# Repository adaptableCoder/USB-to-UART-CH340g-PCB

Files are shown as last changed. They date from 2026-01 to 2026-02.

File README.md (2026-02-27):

# USB to UART Converter (CH340G)

A compact **USB-to-UART adapter** based on the **CH340G**, implemented as a **USB-A edge connector board**.
Fabrication files have been generated; board fabrication is pending.

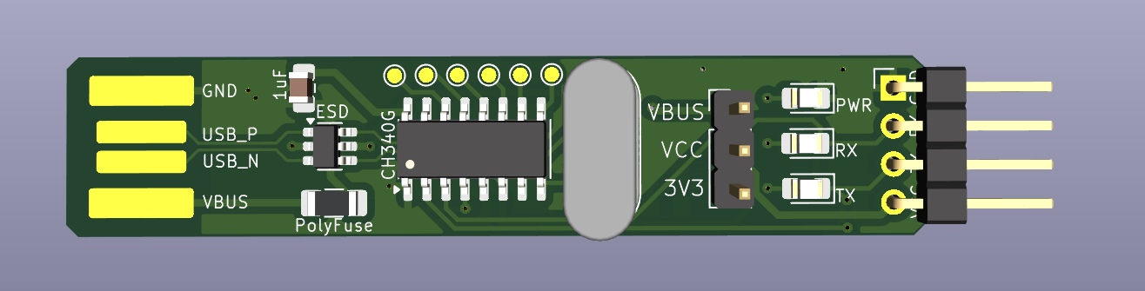
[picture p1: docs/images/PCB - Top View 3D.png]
PCB Top 3D View

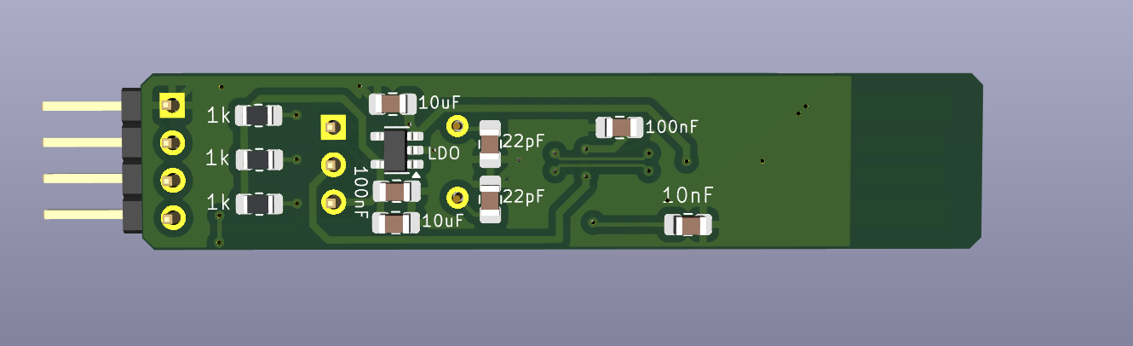
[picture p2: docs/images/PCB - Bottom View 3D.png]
PCB Bottom 3D View

---

## Overview

This project implements a reliable USB-to-UART interface suitable for development, debugging, and embedded bring-up tasks.
Unlike typical breakout boards, this design uses a **USB-A edge connector**, allowing direct insertion into a host USB port without a cable.

The board supports both **5 V and 3.3 V UART logic levels** via jumper selection.

---

## Key Features

* CH340G USB-to-UART bridge
* USB-A **edge connector** (ENIG finish, bevelled)
* Jumper-selectable UART logic level (5 V / 3.3 V)
* On-board 3.3 V LDO
* USB ESD protection
* Polyfuse on VBUS for over-current protection
* Status LEDs (Power, TX, RX)
* RTS / CTS / DTR / DSR signals exposed
* 2-layer PCB, 1.6 mm thickness

---

## Design Tools Used

- KiCad (schematic capture, PCB layout, Gerber generation)

---

## Design Highlights

* **Grounding strategy**

  * Ground stitching vias near USB connector, ESD, and IC
  * Controlled return paths for high-speed signals

* **Clock integrity**

  * 12 MHz crystal placed close to XI/XO pins
  * Symmetric routing and tight loop area
  * Dedicated ground vias for crystal capacitors

* **Manufacturability**

  * ENIG finish selected for USB edge reliability
  * Bevelled edge specified for connector durability
  * Clean DRC-verified Gerber output

---

## Repository Structure

```
usb-to-uart-ch340g-pcb/
├── README.md
├── LICENSE
├── docs/
│   ├── images/
│   └── design-notes.md
├── schematic/
│   └── usb-to-uart-ch340g_schematic.pdf
├── pcb/
│   └── layout_screenshots/
├── fabrication/
│   ├── USB-to-UART-CH340G_Gerbers.zip
│   └── fab-notes.txt
├── datasheet/
│   └── CH340G_datasheet.pdf
└── KiCAD files/
    ├── usb-to-uart.kicad_pro
    ├── usb-to-uart.kicad_sch
    ├── usb-to-uart.kicad_prl
    └── usb-to-uart.kicad_pcb
```
---

## Fabrication Details

* Layers: 2
* Board thickness: 1.6 mm
* Copper weight: 1 oz
* Surface finish: ENIG
* USB edge connector: bevelled
* Solder mask: standard

---

## References and Attribution

* The USB-A edge connector footprint is **adapted from an open-source KiCad footprint library**. The original library is referenced here for attribution: https://github.com/vasya-zh/PCB-Edge-USB-connector-KiCad-library

* Component selection and implementation follow the **WCH CH340G datasheet** and standard USB Full-Speed design guidelines.

* Some YouTube tutorials and online articles on USB-to-UART designs were consulted during development.<br/>
[PCB Cupid](https://www.youtube.com/playlist?list=PLn6004q9oeqGl91KifK6xHGuqvXGb374G) <br/>
[Hardik Seth](https://www.youtube.com/@DIYwithHardik) <br/>
[Electronics Globe](https://www.youtube.com/@electronicsglobeofficial)

---

## License

This project is released under the **MIT License** unless stated otherwise.
Third-party references retain their respective licenses.

---

## Notes

This project was built as a **practical hardware design exercise**, with emphasis on finishing a complete, manufacturable PCB rather than producing a minimal demo board.
Future revisions may explore USB-C support or auto-voltage sensing.

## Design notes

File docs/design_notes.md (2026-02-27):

# Design Notes — USB to UART Converter (CH340G)

This document summarizes the key design decisions and constraints considered while developing this USB-to-UART converter.

---

## USB Interface

- USB Full-Speed (12 Mbps) interface implemented using CH340G.
- USB-A edge connector used instead of a cabled receptacle to reduce mechanical complexity and improve robustness.
- ENIG surface finish and bevelled edge specified for reliable insertion and wear resistance.
- USB D+ / D− routed as a short, parallel pair on the top layer with:
  - Consistent spacing
  - Continuous ground reference underneath

---

## Grounding Strategy

- Bottom copper layer used as the primary ground reference plane.
- Ground plane continuity preserved under USB data lines and crystal region.
- Ground stitching vias added near:
  - USB GND finger
  - ESD protection device
  - CH340G ground pins
  - Crystal load capacitors

This minimizes loop inductance and improves EMI and ESD performance.

---

## Clocking (Crystal Oscillator)

- External 12 MHz crystal used, as recommended for CH340G.
- Crystal placed close to XI/XO pins with symmetric routing.
- Load capacitors placed adjacent to the crystal.
- Each capacitor has a dedicated via to the ground plane.
- No signal or power routing under the crystal region.

---

## Power Architecture

- USB VBUS protected using a PPTC polyfuse.
- CH340G powered directly from 5 V (VBUS), following reference designs.
- Internal 3.3 V regulator output (V3 pin) used only for decoupling, not as a system rail.
- External LDO generates 3.3 V for UART header power and external targets.
- Jumper allows selection of UART header supply (5 V or 3.3 V) without affecting CH340G supply.

---

## UART Interface

- TX, RX, RTS, CTS, DTR, and DSR signals exposed via testing points.
- UART logic level selectable between 5 V and 3.3 V using a jumper.

---

## Protection and Reliability

- USB ESD protection diode placed close to connector.
- Polyfuse limits over-current from USB host.
- Decoupling and bulk capacitors placed close to their respective loads.

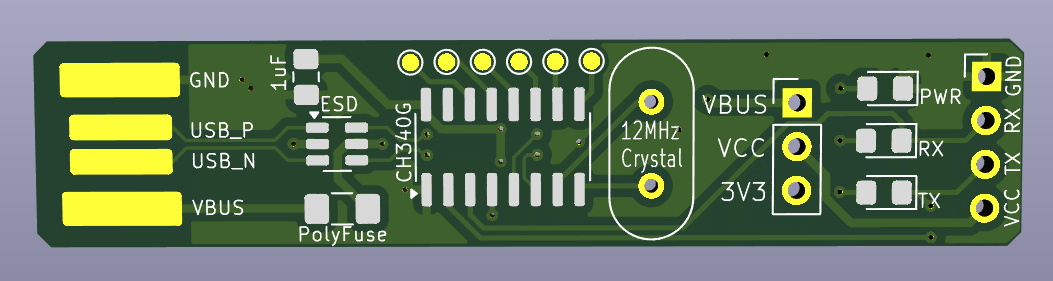
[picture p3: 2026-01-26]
docs/images/PCB - Top View.png

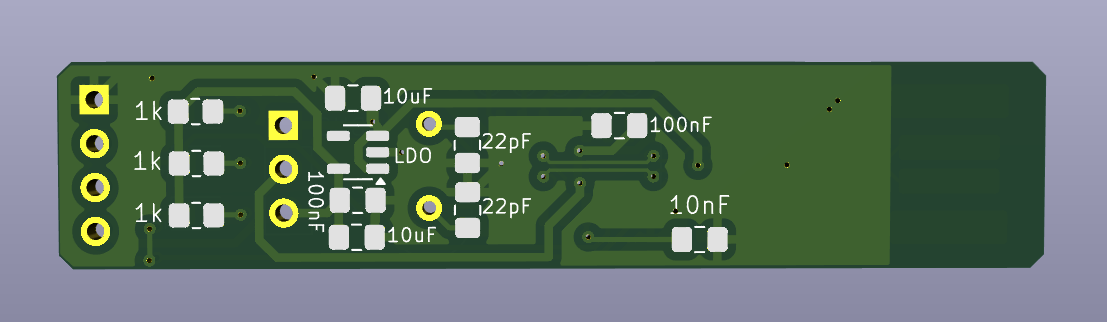
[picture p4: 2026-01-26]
docs/images/PCB - Bottom View.png

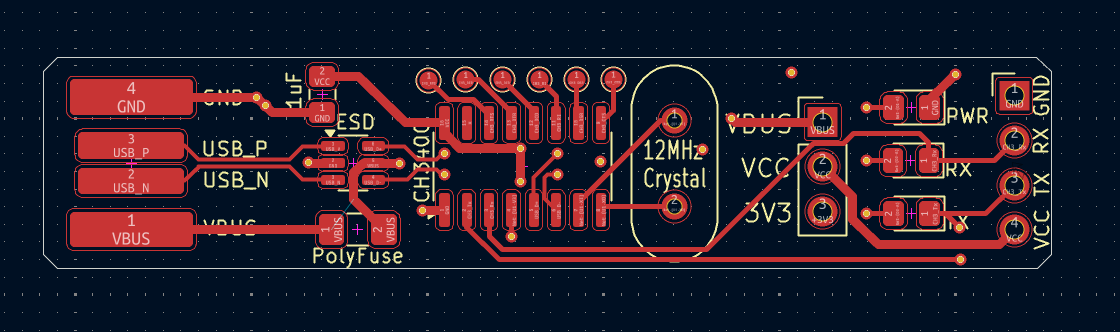
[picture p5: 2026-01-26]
pcb/layout_screenshots/Top Routing.png

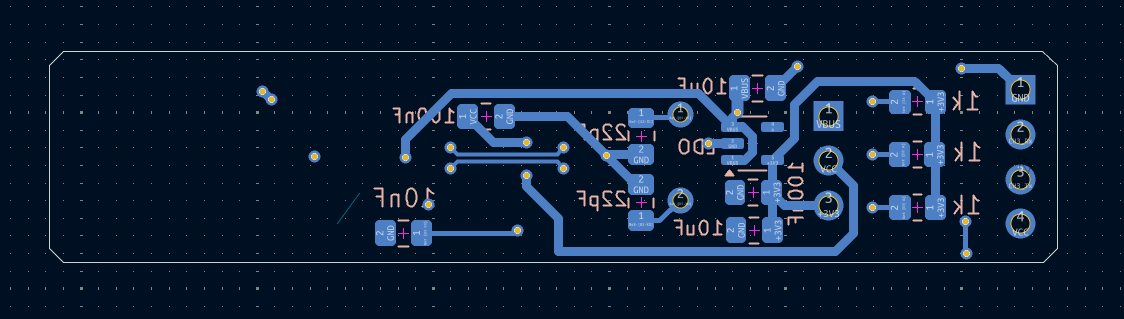
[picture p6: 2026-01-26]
pcb/layout_screenshots/Bottom Routing.png

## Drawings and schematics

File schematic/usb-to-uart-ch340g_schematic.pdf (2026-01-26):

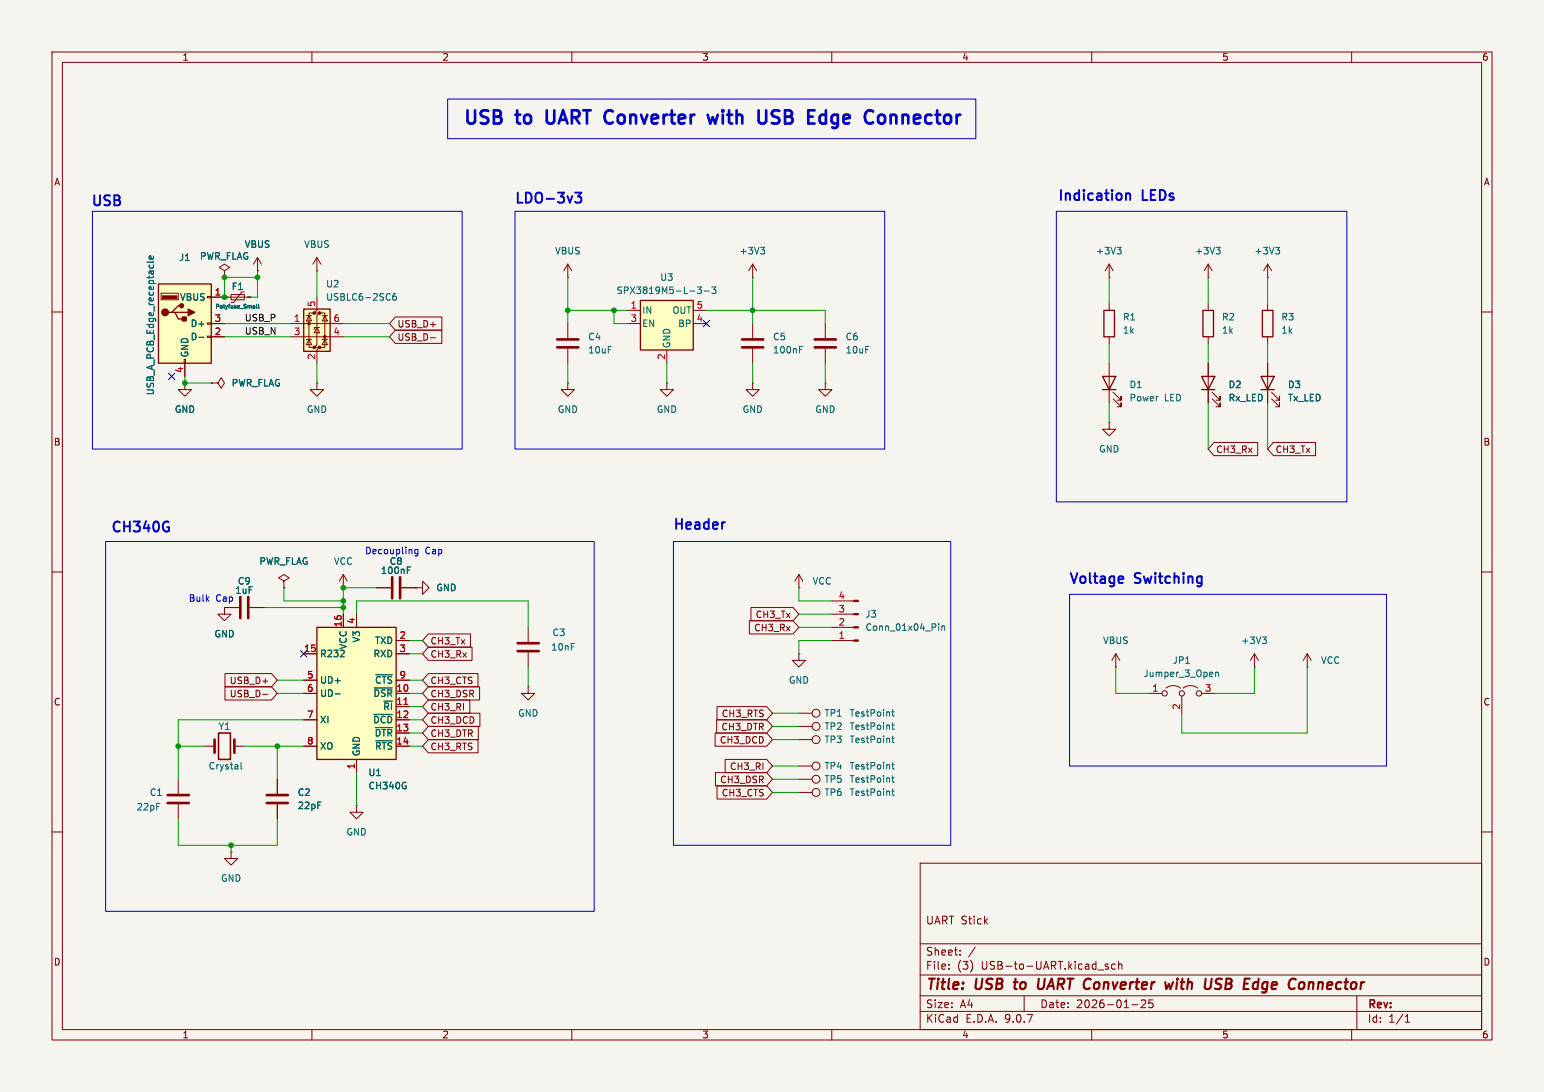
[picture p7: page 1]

USB to UART Converter with USB Edge Connector

1 TXD 2 RXD 3 ~{CTS}9 ~{DSR} 10 ~{RI} 11 ~{DCD} 12 ~{DTR} 13 ~{RTS} 14 C9
Bulk Cap

1 TXD 2 RXD 3 ~{CTS}9 ~{DSR} 10 ~{RI} 11 ~{DCD} 12 ~{DTR} 13 ~{RTS} 14 U1 CH340G C1

Id: 1/1 Title: USB to UART Converter with USB Edge Connector File: (3) USB-to-UART.kicad_sch Sheet: / UART Stick TP4 TestPoint TP6 TestPoint TP5 TestPoint

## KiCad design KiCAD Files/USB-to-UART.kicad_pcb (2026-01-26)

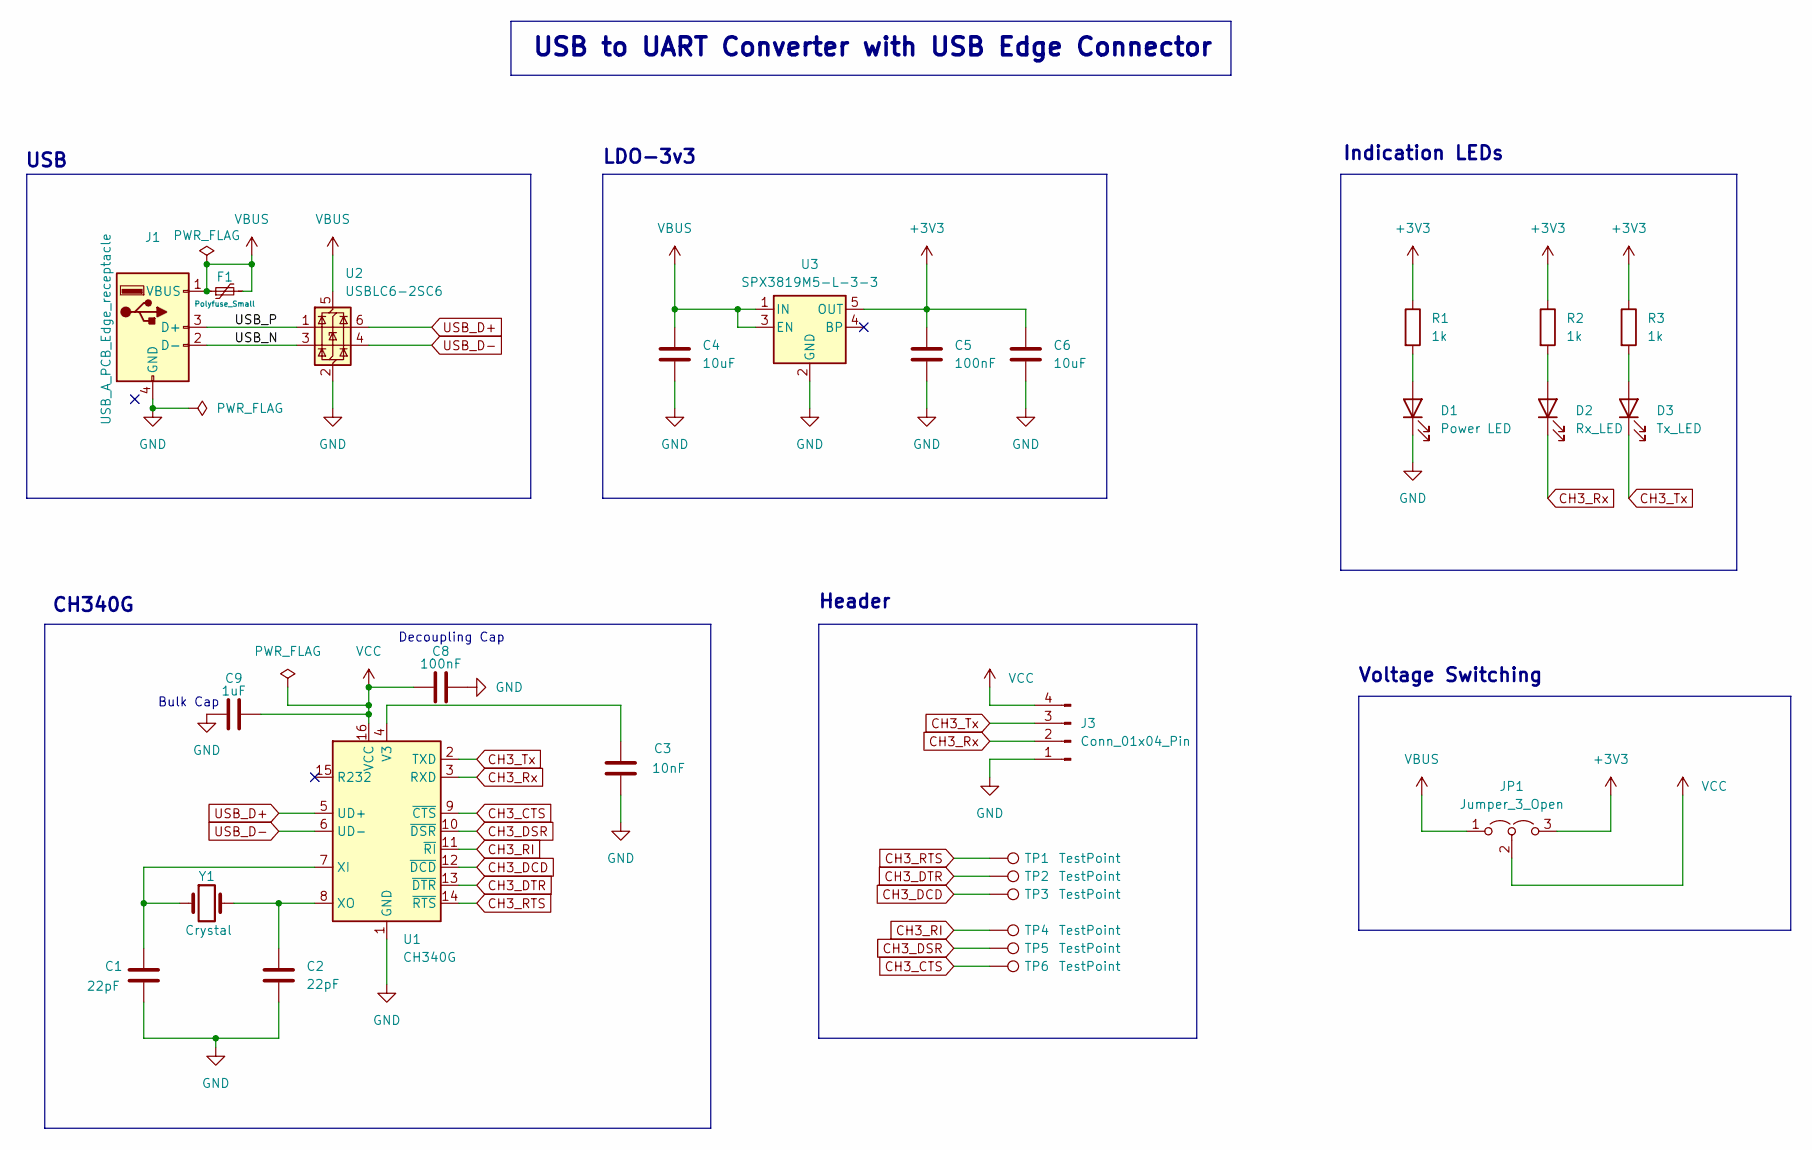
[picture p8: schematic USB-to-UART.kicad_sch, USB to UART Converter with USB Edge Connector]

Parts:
C1, C2: 22pF; C_0805_2012Metric_Pad1.18x1.45mm_HandSolder
C3: 10nF; C_0805_2012Metric_Pad1.18x1.45mm_HandSolder
C4, C6: 10uF; C_0805_2012Metric_Pad1.18x1.45mm_HandSolder
C5, C8: 100nF; C_0805_2012Metric_Pad1.18x1.45mm_HandSolder
C9: 1uF; C_0805_2012Metric_Pad1.18x1.45mm_HandSolder
D1: Power LED; LED_0805_2012Metric_Pad1.15x1.40mm_HandSolder
D2: Rx_LED; LED_0805_2012Metric_Pad1.15x1.40mm_HandSolder
D3: Tx_LED; LED_0805_2012Metric_Pad1.15x1.40mm_HandSolder
F1: Polyfuse_Small; Fuse_1206_3216Metric_Pad1.42x1.75mm_HandSolder
J1: USB_A_PCB_Edge_receptacle
J3: Conn_01x04_Pin; PinHeader_1x04_P2.54mm_Horizontal
JP1: Jumper_3_Open; PinHeader_1x03_P2.54mm_Vertical
R1, R2, R3: 1k; R_0805_2012Metric_Pad1.20x1.40mm_HandSolder
TP1, TP2, TP3, TP4, TP5, TP6: TestPoint; TestPoint_Pad_D1.0mm
U1: CH340G; SOIC-16_3.9x9.9mm_P1.27mm
U2: USBLC6-2SC6; SOT-23-6
U3: SPX3819M5-L-3-3; SOT-23-5
Y1: Crystal; Crystal_HC49-U_Vertical

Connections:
+3V3: C5.1, C6.1, JP1.3 (B), R1.1, R2.1, R3.1, U3.5 (OUT)
/USB_N: J1.2 (D-), U2.3 (I/O2)
/USB_P: J1.3 (D+), U2.1 (I/O1)
CH3_CTS: TP6.1, U1.9 (~CTS)
CH3_DCD: TP3.1, U1.12 (~DCD)
CH3_DSR: TP5.1, U1.10 (~DSR)
CH3_DTR: TP2.1, U1.13 (~DTR)
CH3_RI: TP4.1, U1.11 (~RI)
CH3_RTS: TP1.1, U1.14 (~RTS)
CH3_Rx: D2.1 (K), J3.2, U1.3 (RXD)
CH3_Tx: D3.1 (K), J3.3, U1.2 (TXD)
GND: C1.2, C2.2, C3.2, C4.2, C5.2, C6.2, C8.2, C9.1, D1.1 (K), J1.4 (GND), J3.1, U1.1 (GND), U2.2 (GND), U3.2 (GND)
unnamed: D1.2 (A), R1.2
unnamed: D2.2 (A), R2.2
unnamed: D3.2 (A), R3.2
unnamed: C3.1, U1.4 (V3)
unnamed: C1.1, U1.7 (XI), Y1.1
unnamed: C2.1, U1.8 (XO), Y1.2
USB_D+: U1.5 (UD+), U2.6 (I/O1)
USB_D-: U1.6 (UD-), U2.4 (I/O2)
VBUS: C4.1, F1.1, F1.2, J1.1 (VBUS), JP1.1 (A), U2.5 (VBUS), U3.1 (IN), U3.3 (EN)
VCC: C8.1, C9.2, J3.4, JP1.2 (C), U1.16 (VCC)

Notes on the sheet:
CH340G
Decoupling Cap
Header
USB
Voltage Switching
USB to UART Converter with USB Edge Connector
Bulk Cap
LDO-3v3
Indication LEDs

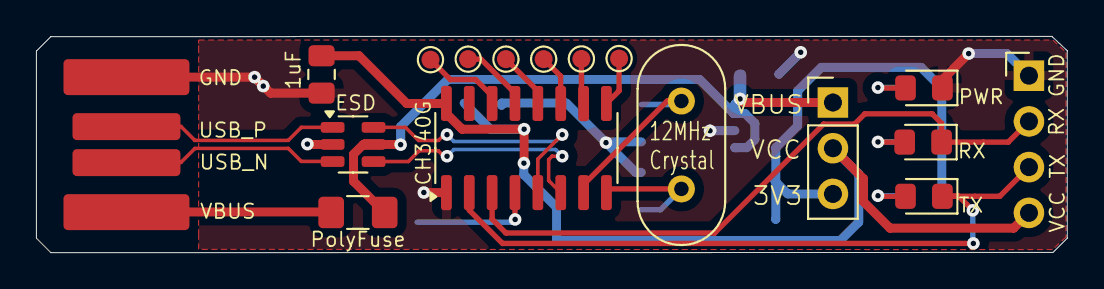
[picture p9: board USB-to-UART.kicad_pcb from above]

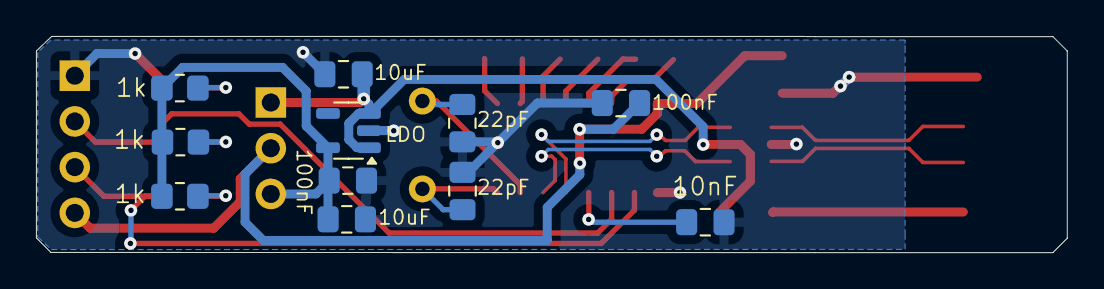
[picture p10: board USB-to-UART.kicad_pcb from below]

Board: 2 copper layers, 57.3 x 12.0 mm, 28 parts (11 on the bottom side), 22 nets.

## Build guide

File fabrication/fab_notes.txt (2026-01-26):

Project: USB to UART Converter (CH340G)

PCB Specifications:
- Layers: 2
- Board thickness: 1.6 mm
- Copper weight: 1 oz (top and bottom)
- Base material: FR4
- Surface finish: ENIG

USB Edge Connector:
- USB-A edge card connector
- Bevelled edge required
- No solder mask or silkscreen on edge fingers

Manufacturing Notes:
- Standard solder mask both sides
- No impedance-controlled traces required
- Drill files provided separately for PTH and NPTH
- Gerber X2 format with job file included

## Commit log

2026-02-14 Readme updated with PCB 3D Pics
2026-02-27 Updated README.md for KiCAD files
    [USB-to-UART.kicad_pcb, USB-to-UART.kicad_sch]
